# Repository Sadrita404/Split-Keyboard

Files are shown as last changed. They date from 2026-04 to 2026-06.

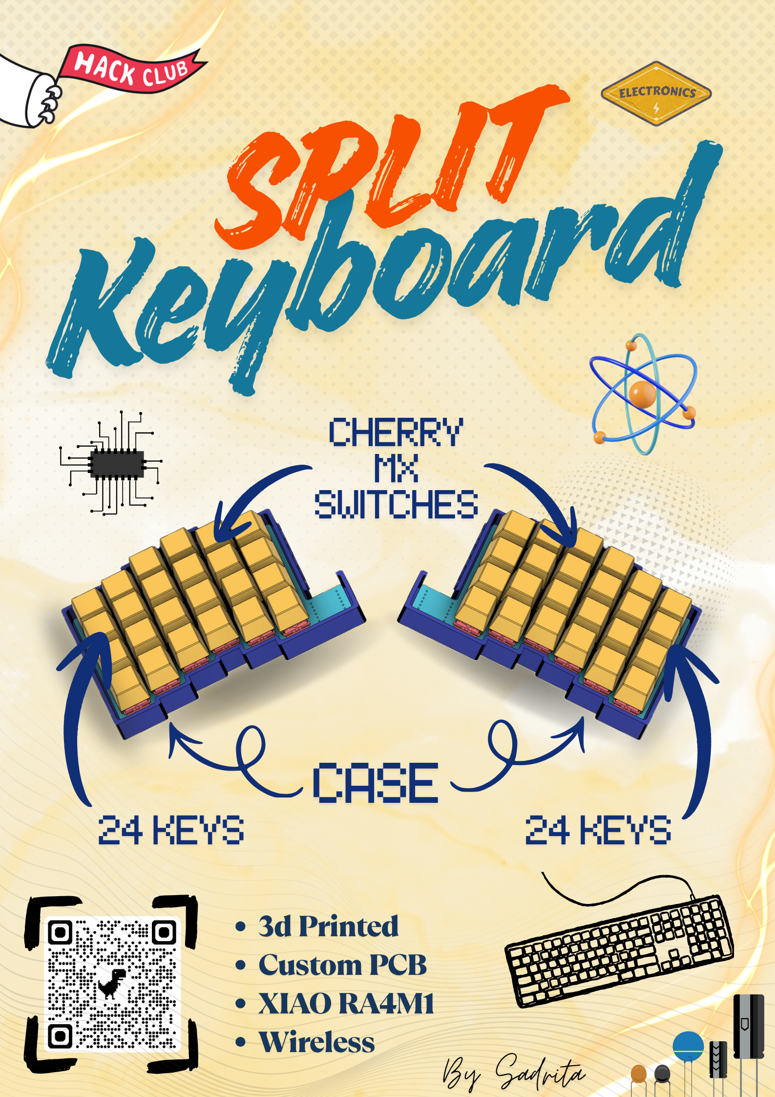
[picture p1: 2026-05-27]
IMAGES/Poster Split Keyboard.png

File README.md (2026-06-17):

Split Keyboard (1)

---

|Title | Split-Keyboard|
|:-- |:--|
|Author | Sadrita Neogi|

## Overview

This split keyboard is basically fixes everything annoying about standard typing. We took the logic of an ortholinear grid (where everything is predictable) and mashed it together with a column stagger that actually matches how long your fingers are.
**For me this type of form factor keyboard is good for long hours of typing**

---

## Project Inspiration
Screenshot 2026-04-22 at 12 03 37 AM

### I want to make an Keyboadr which is like this (I just draw it out of my imagination )

---
## PCB 

### For getting started I have choose Kicad for designing the PCB also the schematic 

Left sch

--- 

Right sch

---

Screenshot 2026-04-22 at 10 36 53 PM

---

Screenshot 2026-04-22 at 10 12 50 PM

---

## Case

### For the Case I have choose Fusion 360 for this project

---

Screenshot 2026-04-22 at 10 55 04 PM

---
## Top Plate 

Screenshot 2026-05-07 at 11 12 01 AM

---

### After Assembly

Screenshot 2026-05-07 at 11 08 56 AM

---

Split Keyboard (2)

---
## Assembly Instructions :-
1) First we need to get the PCB and then startrd soldering the **Schottky Diodes** to all the pads of the PCB .

2) After that we need to add the **SeeedStudio XIAO RA4M1** to the designated spot on the PCb .

3) After that we will need to connect the SeeedStudio XIAO RA4M1 to the PC and upload the code given in the [FIRMWARE](https://github.com/Sadrita404/Split-Keyboard/tree/main/FIRMWARE) and use **Arduino IDE** to upload the code .

4) Then will will solder the battery to the designated spot on the PCb .

5) After that we will take our 3d Printed PCB Case and and screw the pcb to the case .

6) Then we will add the 3d Printed top Plate to the Case and fix it.

7) After that we will put the 5pin Switches in the PCb gently , to all the Places.

8) And then we will add the Key Caps to the Switches.

9) The last step connect the Keyboard to the PC and start using it...

---

SPlit

##### [Lapse For Poster Design ](https://lapse.hackclub.com/timelapse/cM2Pj_Yv2DLz)

---
## Bill Of Material (BOM)
|Name	|Purpose|	Qty	|Total Price (USD)	| Component Link	 |Distributor |
| :-- | :-- | :-- |  :-- | :-- | :-- |
| 3.7V 500mAh 1S LiPo Battery  | For Powering up the keyboard | 2 | $5.57 |  [Link](https://robu.in/product/500mah-pcm-protected-micro-li-po-battery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) |  Robu.in |
| PCB  | PCB	For making the keyboard and adding the switches  | 1 | $20 |  [Link](https://cart.jlcpcb.com/shopcart/cart/) | All PCB |
| Keycaps | 	For attaching it to the switches | 1 | $16.00 | [Link](https://stackskb.com/store/white-grey-and-yellow-double-shot-abs-cherry-profile-keycaps/) | Stackskb.com |
| Hot Swap Sockets(10)  |  For Connecting the Switch with the PCB | 5 | $6.19 | [Link](https://neomacro.in/products/kailh-choc-pg1350-hot-swap-sockets?variant=48049369907478) | Neomacro.in |
| 5 Pin Switches(10) |  For the PCB where I need to place the Switch | 5 | $18.80 | [Link](https://neomacro.in/products/swk-ghost-dragons?variant=50342929039638) | Neomacro.in |
| Single row header Pin |  	For connecting the Seeed Studio with the pcb | 2 | $0.19 | [Link](https://robu.in/product/2-54mm-1x40-pin-male-single-row-straight-short-header-strip-pack-of-3) | Robu.in |
| Schottky Diodes | For PCB ( registering the value of the key press) | 50 | $1.16 | [Link](https://robu.in/product/1n5819hw-tech-public-40v-900mv3a-1a-sod-123-schottky-diodes-rohs) |  Robu.in |
| SeeedStudio XIAO RA4M1 | For Controlling the PCB  | 2 | $13.27 | [Link](https://robu.in/product/seeedstudio-xiao-ra4m1-smallest-dev-board-based-on-32-bit-renesas-ra4m1-arduino-ide-ready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) | Robu.in |
|  Total | | | | | $95.74 |
|  Round Off Total (USD) | | | | | $100  |

## For 3d Printing I have use Legion where the cost is included in the Shipping
|Tax (USD)| Shipping (USD)|
|:-- | :--|
|$6.12  | $6.48|
| Round Off Total (USD) |  $100  |

---

## Project Under [Hack Club](https://hackclub.com/)

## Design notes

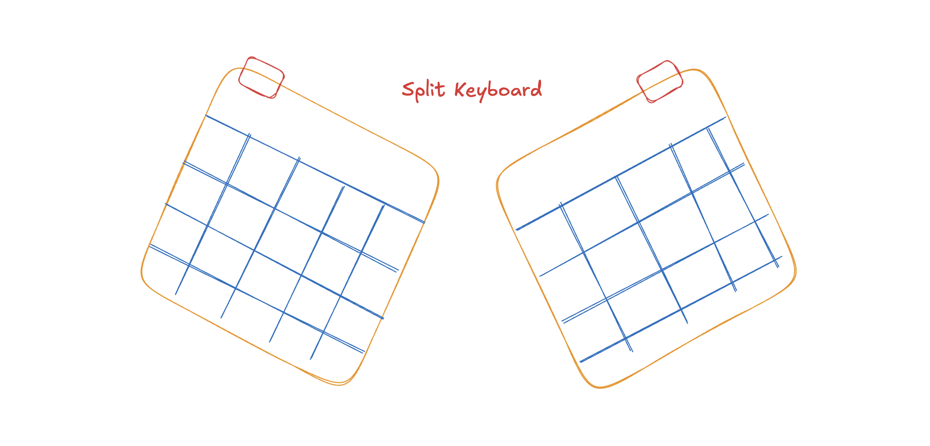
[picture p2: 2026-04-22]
IMAGES/Design.png

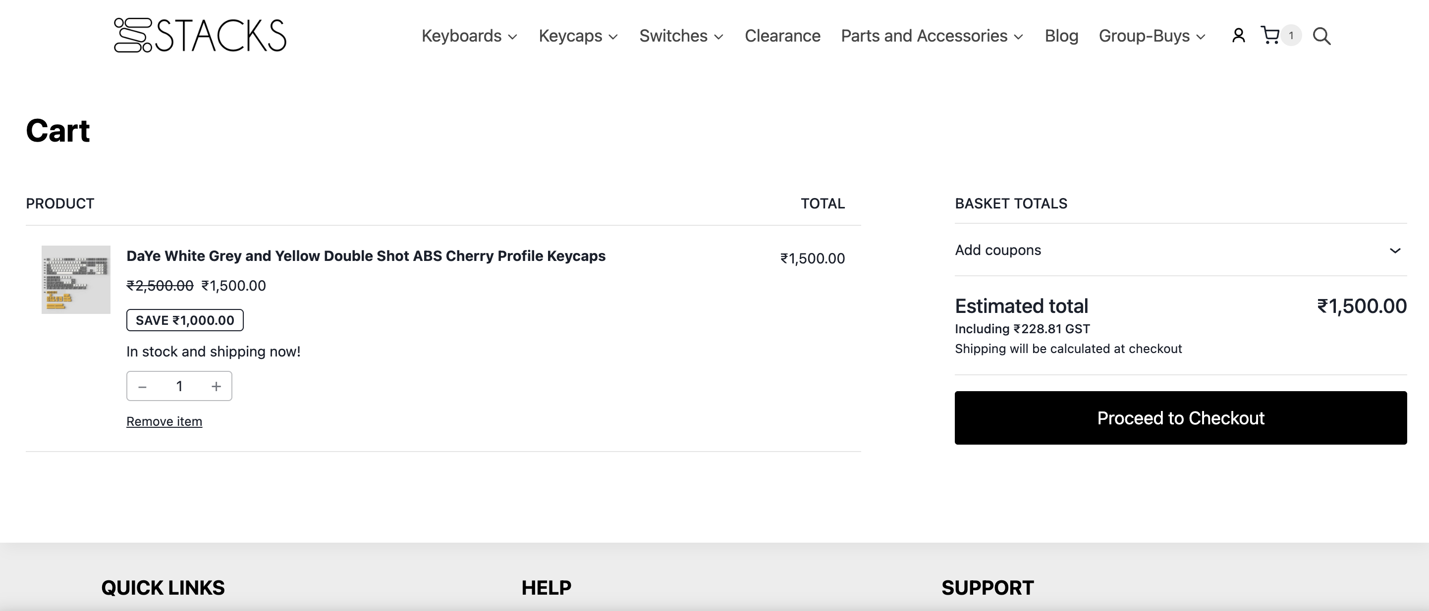
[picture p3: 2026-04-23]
IMAGES/Bill 4.png

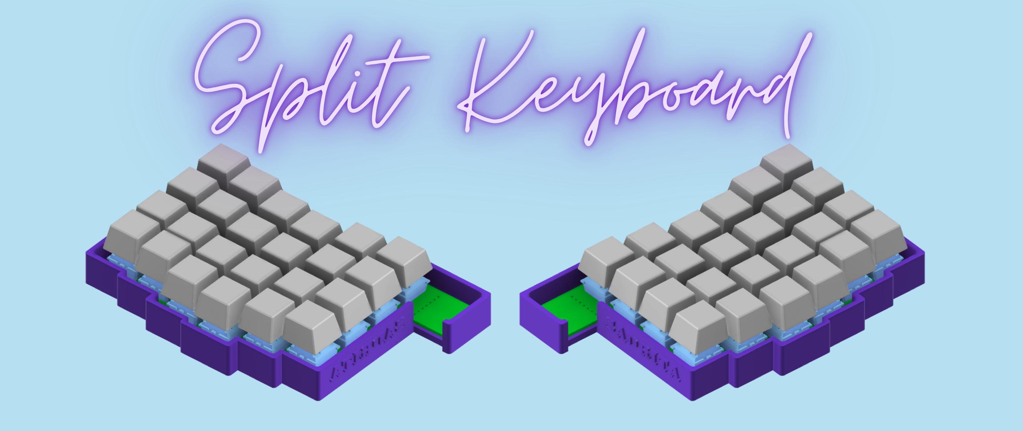
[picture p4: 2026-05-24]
IMAGES/Split Keyboard (1).png

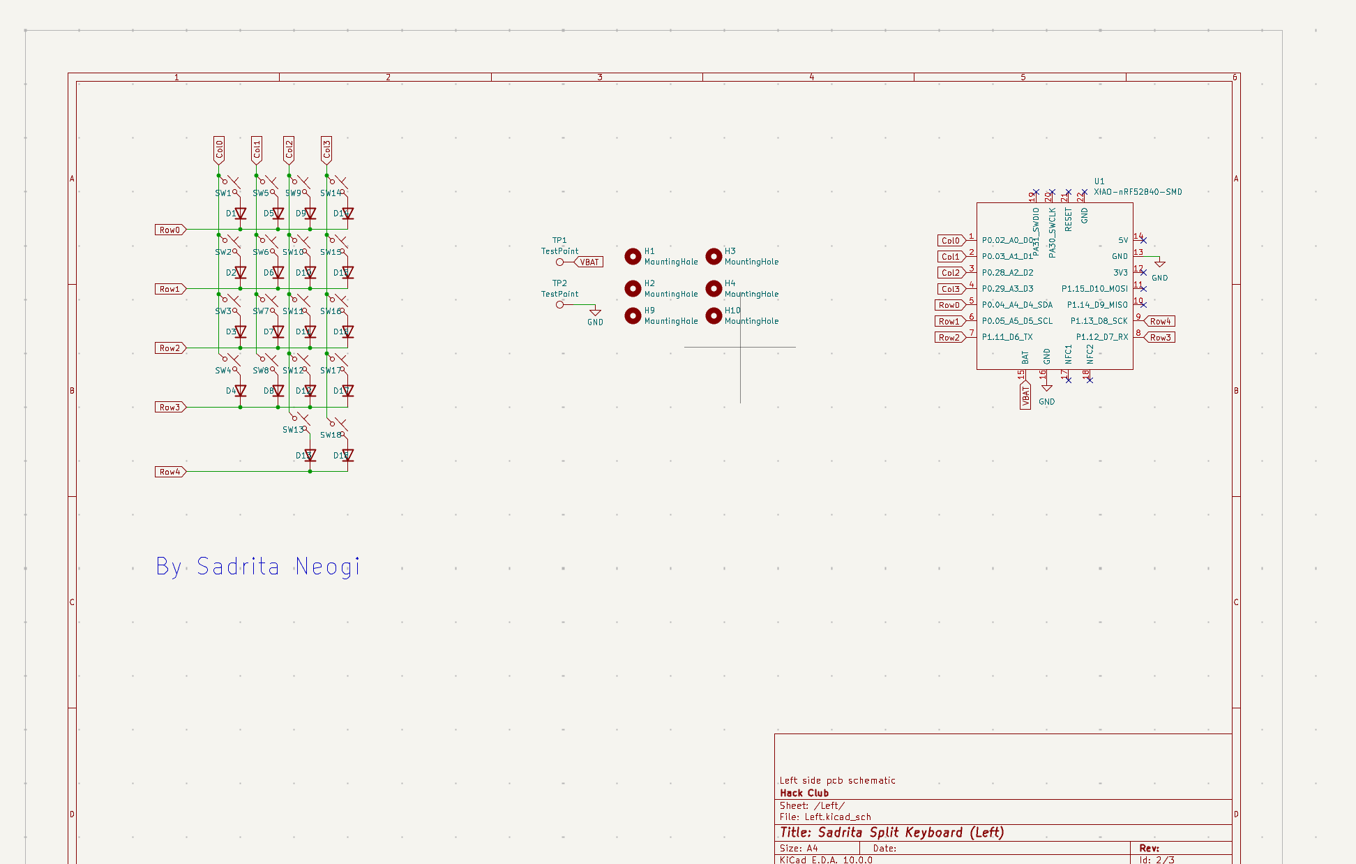
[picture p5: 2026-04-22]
IMAGES/Left sch.png

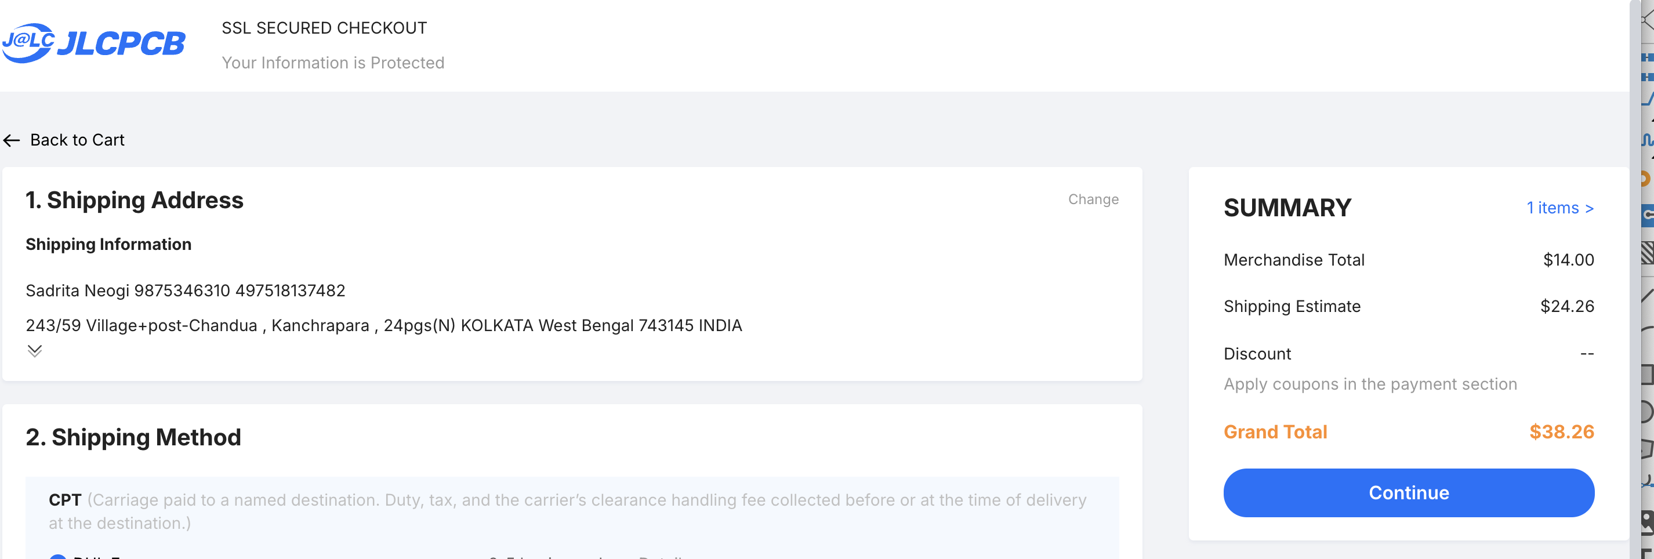
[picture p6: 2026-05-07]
IMAGES/Bill 1.png

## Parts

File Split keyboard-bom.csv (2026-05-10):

Name | Purpose | Quantity | Total Cost (USD) | Link | Distributor
PCB | For making the keyboard and adding the switches | 1 | 20 | https://www.allpcb.com/cart?protype=2&upfileid=809563 | ALL PCB
3.7V 500mAh 1S LiPo Battery | For Powering up the keyboard | 2 | 5.57 | https://robu.in/product/500mah-pcm-protected-micro-li-po-battery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 | Robu.in
Keycaps | For attaching it to the switches | 1 | 16.00 | https://stackskb.com/store/white-grey-and-yellow-double-shot-abs-cherry-profile-keycaps/ | Stackskb.com
Hot Swap Sockets(10) | For Connecting the Switch with the PCB | 5 | 6.19 | https://neomacro.in/products/kailh-choc-pg1350-hot-swap-sockets?variant=48049369907478 | Neomacro.in
5 Pin Switches(10) | For the PCB where I need to place the Switch | 5 | 18.80 | https://neomacro.in/products/swk-ghost-dragons?variant=50342929039638 | Neomacro.in
Single row header Pin | For connecting the Seeed Studio with the pcb | 2 | 0.19 | https://robu.in/product/2-54mm-1x40-pin-male-single-row-straight-short-header-strip-pack-of-3 | Robu.in
Schottky Diodes | For PCB ( registering the value of the key press) | 50 | 1.16 | https://robu.in/product/1n5819hw-tech-public-40v-900mv3a-1a-sod-123-schottky-diodes-rohs | Robu.in
SeeedStudio XIAO RA4M1 | For Controlling the PCB | 2 | 13.27 | https://robu.in/product/seeedstudio-xiao-ra4m1-smallest-dev-board-based-on-32-bit-renesas-ra4m1-arduino-ide-ready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 | Robu.in

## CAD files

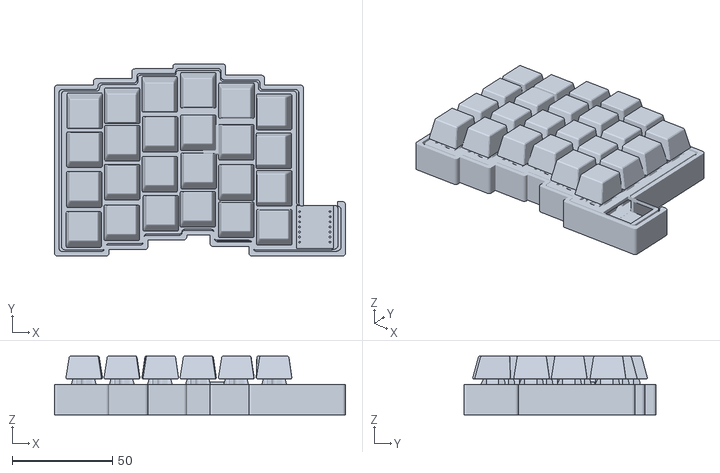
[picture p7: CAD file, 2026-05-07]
CAD/ASSEMBLY/Assemble with Key Caps.stl
145.5 x 96.1 x 29.4

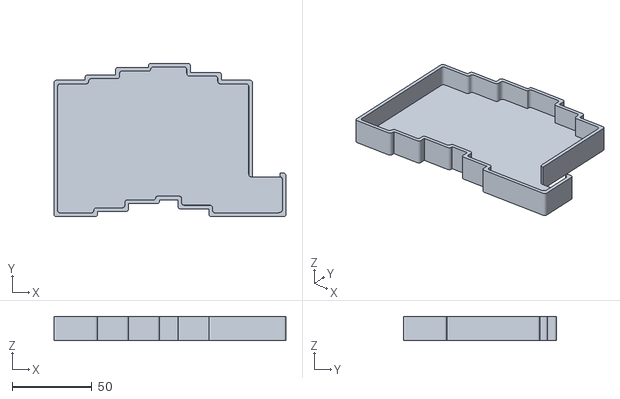
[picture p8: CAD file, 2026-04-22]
CAD/Case/Left Case.stl
145.5 x 96.1 x 15.3

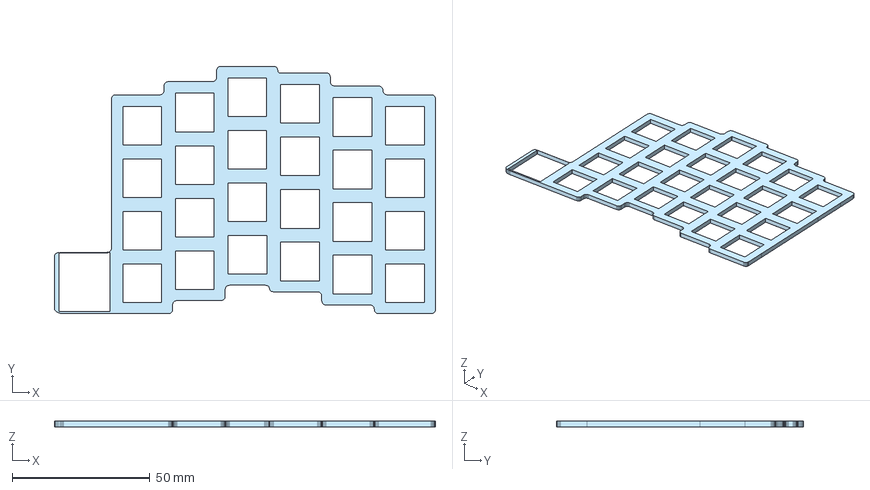
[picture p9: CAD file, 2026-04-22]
CAD/Plate/Plate Right.step
138.1 x 89.6 x 2.00 mm

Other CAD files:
CAD/Case/Right Case.stl
CAD/Plate/Plate Left.step
CAD/ASSEMBLY/Assemble with Key Caps.f3z
CAD/Case/Case f3d file.f3d
CAD/Plate/Plate Left.stl
CAD/Plate/Plate Right.stl

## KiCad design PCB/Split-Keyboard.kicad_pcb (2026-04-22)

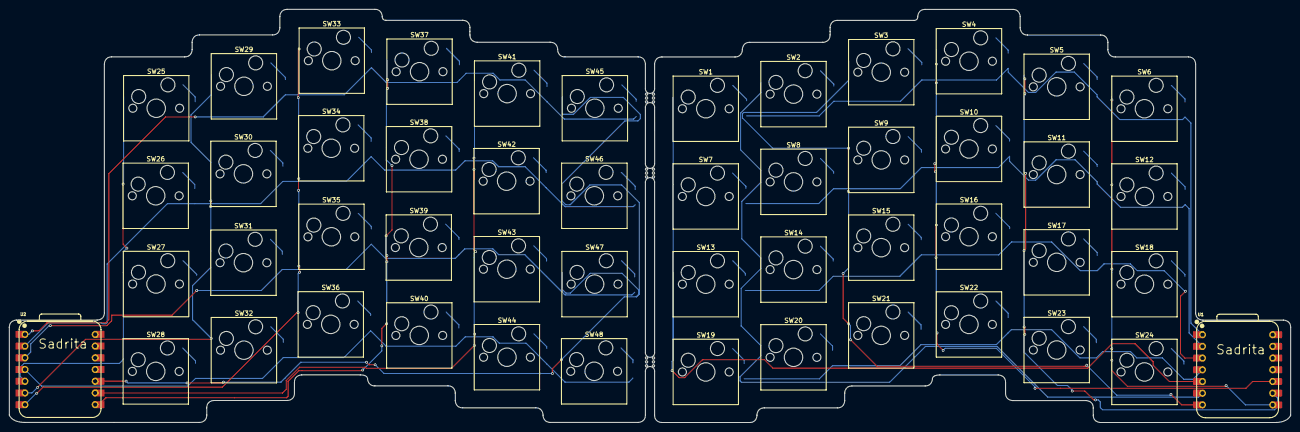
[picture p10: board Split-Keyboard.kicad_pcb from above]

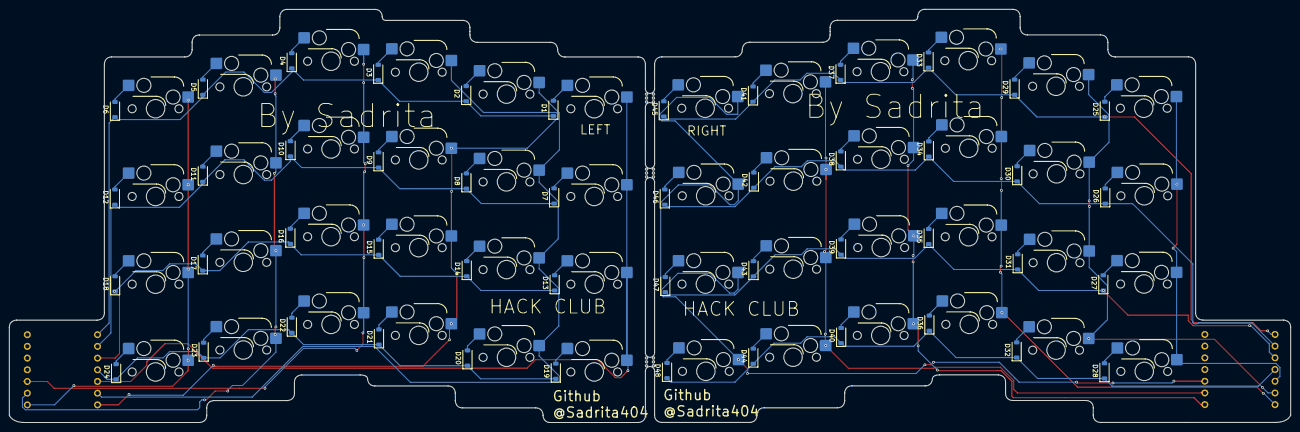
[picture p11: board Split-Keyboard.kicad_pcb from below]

Board: 2 copper layers, 278.2 x 89.7 mm, 101 parts (48 on the bottom side), 68 nets.

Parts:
B1, B2, B3: MouseBite; MouseBite-Slot_2.0x2.0mm_outset_D0.5mm_P0.85mm_3h
D1, D2, D3, D4, D5, D6, D7, D8, D9, D10, D11, D12, D13, D14, D15, D16, D17, D18, D19, D20, D21, D22, D23, D24, D25, D26, D27, D28, D29, D30, D31, D32, D33, D34, D35, D36, D37, D38, D39, D40, D41, D42, D43, D44, D45, D46, D47, D48: D; D_SOD-123
SW1, SW2, SW3, SW4, SW5, SW6, SW7, SW8, SW9, SW10, SW11, SW12, SW13, SW14, SW15, SW16, SW17, SW18, SW19, SW20, SW21, SW22, SW23, SW24, SW25, SW26, SW27, SW28, SW29, SW30, SW31, SW32, SW33, SW34, SW35, SW36, SW37, SW38, SW39, SW40, SW41, SW42, SW43, SW44, SW45, SW46, SW47, SW48: SW_Push_45deg; SW_Hotswap_Kailh_MX
U1, U2: XIAO-nRF52840-DIP

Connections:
Col0: SW1.1, SW7.1, SW13.1, SW19.1, U1.5 (P0.04_AIN2_A4_D4)
Col1: SW2.1, SW8.1, SW14.1, SW20.1, U1.6 (P0.05_AIN3_A5_D5)
Col2: SW3.1, SW9.1, SW15.1, SW21.1, U1.7 (P1.11_TX_D6)
Col3: SW4.1, SW10.1, SW16.1, SW22.1, U1.10 (P1.14_MISO_D9)
Col4: SW5.1, SW11.1, SW17.1, SW23.1, U1.9 (P1.13_SCK_D8)
Col5: SW6.1, SW12.1, SW18.1, SW24.1, U1.8 (P1.12_RX_D7)
Col6: SW25.1, SW26.1, SW27.1, SW28.1, U2.5 (P0.04_AIN2_A4_D4)
Col7: SW29.1, SW30.1, SW31.1, SW32.1, U2.6 (P0.05_AIN3_A5_D5)
Col8: SW33.1, SW34.1, SW35.1, SW36.1, U2.7 (P1.11_TX_D6)
Col9: SW37.1, SW38.1, SW39.1, SW40.1, U2.8 (P1.12_RX_D7)
Col10: SW41.1, SW42.1, SW43.1, SW44.1, U2.9 (P1.13_SCK_D8)
Col11: SW45.1, SW46.1, SW47.1, SW48.1, U2.10 (P1.14_MISO_D9)
unnamed: D1.2 (A), SW1.2
unnamed: D2.2 (A), SW2.2
unnamed: D3.2 (A), SW3.2
unnamed: D4.2 (A), SW4.2
unnamed: D5.2 (A), SW5.2
unnamed: D6.2 (A), SW6.2
unnamed: D7.2 (A), SW7.2
unnamed: D8.2 (A), SW8.2
unnamed: D9.2 (A), SW9.2
unnamed: D10.2 (A), SW10.2
unnamed: D11.2 (A), SW11.2
unnamed: D12.2 (A), SW12.2
unnamed: D13.2 (A), SW13.2
unnamed: D14.2 (A), SW14.2
unnamed: D15.2 (A), SW15.2
unnamed: D16.2 (A), SW16.2
unnamed: D17.2 (A), SW17.2
unnamed: D18.2 (A), SW18.2
unnamed: D19.2 (A), SW19.2
unnamed: D20.2 (A), SW20.2
unnamed: D21.2 (A), SW21.2
unnamed: D22.2 (A), SW22.2
unnamed: D23.2 (A), SW23.2
unnamed: D24.2 (A), SW24.2
unnamed: D25.2 (A), SW25.2
unnamed: D26.2 (A), SW26.2
unnamed: D27.2 (A), SW27.2
unnamed: D28.2 (A), SW28.2
unnamed: D29.2 (A), SW29.2
unnamed: D30.2 (A), SW30.2
unnamed: D31.2 (A), SW31.2
unnamed: D32.2 (A), SW32.2
unnamed: D33.2 (A), SW33.2
unnamed: D34.2 (A), SW34.2
unnamed: D35.2 (A), SW35.2
unnamed: D36.2 (A), SW36.2
unnamed: D37.2 (A), SW37.2
unnamed: D38.2 (A), SW38.2
unnamed: D39.2 (A), SW39.2
unnamed: D40.2 (A), SW40.2
unnamed: D41.2 (A), SW41.2
unnamed: D42.2 (A), SW42.2
unnamed: D43.2 (A), SW43.2
unnamed: D44.2 (A), SW44.2
unnamed: D45.2 (A), SW45.2
unnamed: D46.2 (A), SW46.2
unnamed: D47.2 (A), SW47.2
unnamed: D48.2 (A), SW48.2
Row0: D1.1 (K), D2.1 (K), D3.1 (K), D4.1 (K), D5.1 (K), D6.1 (K), U1.1 (P0.02_AIN0_LOW_A0_D0)
Row1: D7.1 (K), D8.1 (K), D9.1 (K), D10.1 (K), D11.1 (K), D12.1 (K), U1.2 (P0.03_AIN1_LOW_A1_D1)
Row2: D13.1 (K), D14.1 (K), D15.1 (K), D16.1 (K), D17.1 (K), D18.1 (K), U1.3 (P0.28_AIN4_LOW_A2_D2)
Row3: D19.1 (K), D20.1 (K), D21.1 (K), D22.1 (K), D23.1 (K), D24.1 (K), U1.4 (P0.29_AIN5_LOW_A3_D3)
Row4: D25.1 (K), D29.1 (K), D33.1 (K), D37.1 (K), D41.1 (K), D45.1 (K), U2.1 (P0.02_AIN0_LOW_A0_D0)
Row5: D26.1 (K), D30.1 (K), D34.1 (K), D38.1 (K), D42.1 (K), D46.1 (K), U2.2 (P0.03_AIN1_LOW_A1_D1)
Row6: D27.1 (K), D31.1 (K), D35.1 (K), D39.1 (K), D43.1 (K), D47.1 (K), U2.3 (P0.28_AIN4_LOW_A2_D2)
Row7: D28.1 (K), D32.1 (K), D36.1 (K), D40.1 (K), D44.1 (K), D48.1 (K), U2.4 (P0.29_AIN5_LOW_A3_D3)

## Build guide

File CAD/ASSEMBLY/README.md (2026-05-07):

### For the reference after addding the keycaps the final modelis looking like :- 

---

Screenshot 2026-05-07 at 11 08 56 AM

---

Screenshot 2026-05-07 at 11 09 15 AM

---

Screenshot 2026-05-07 at 11 09 07 AM

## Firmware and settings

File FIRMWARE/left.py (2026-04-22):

import board

from kmk.kmk_keyboard import KMKKeyboard
from kmk.keys import KC
from kmk.modules.layers import Layers
from kmk.scanners import DiodeOrientation

keyboard = KMKKeyboard()

layers = Layers()
keyboard.modules.append(layers)

keyboard.row_pins = (board.D0, board.D1, board.D2, board.D3)
keyboard.col_pins = (board.D4, board.D5, board.D6, board.D9, board.D8, board.D7)

keyboard.diode_orientation = DiodeOrientation.COL2ROW
keyboard.keymap = [

# Layer 0
[
KC.ESC, KC.Q, KC.W, KC.E, KC.R, KC.T,
KC.TAB, KC.A, KC.S, KC.D, KC.F, KC.G,
KC.LSHIFT, KC.Z, KC.X, KC.C, KC.V, KC.B,
KC.LCTRL, KC.LGUI, KC.LALT, KC.MO(1), KC.MO(2), KC.SPACE
],

# Layer 1 (Fn)
[
KC.GRAVE, KC.N1, KC.N2, KC.N3, KC.N4, KC.N5,
KC.TRNS, KC.LEFT, KC.DOWN, KC.UP, KC.RIGHT, KC.TRNS,
KC.TRNS, KC.TRNS, KC.TRNS, KC.TRNS, KC.TRNS, KC.TRNS,
KC.TRNS, KC.HOME, KC.END, KC.TRNS, KC.TRNS, KC.ENTER
],

# Layer 2
[
KC.F1, KC.F2, KC.F3, KC.F4, KC.F5, KC.F6,
KC.TRNS, KC.TRNS, KC.TRNS, KC.TRNS, KC.TRNS, KC.TRNS,
KC.TRNS, KC.TRNS, KC.TRNS, KC.TRNS, KC.TRNS, KC.TRNS,
KC.TRNS, KC.TRNS, KC.TRNS, KC.TRNS, KC.TRNS, KC.TRNS
]

]


if __name__ == "__main__":
    keyboard.go()

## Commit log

2026-05-01 Uploaded the .f3d file and the top plate
2026-05-07 Create ASSEMBLE
2026-05-07 STEP File with key caps added to the final model
    [Assemble with Key Caps.stl]
2026-05-07 PCB bill added
2026-05-10 Added the f3d file for the case
    [Case f3d file.f3d]
2026-05-10 Update Split keyboard-bom.csv
    [Split keyboard-bom.csv]
2026-05-10 Added the f3z file
    [Assemble with Key Caps.f3z]
2026-05-10 Added the GERBER in zip file
